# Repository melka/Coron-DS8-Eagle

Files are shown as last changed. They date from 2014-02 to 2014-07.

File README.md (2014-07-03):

# Coron DS8 Clone

Eagle project for the [Coron DS8 Clone by Marc Bareille](http://m.bareille.free.fr/ds7clone/ds8.htm)

[BOM on Mouser](http://www.mouser.com/ProjectManager/ProjectDetail.aspx?AccessID=e1b7458c28)

Block diagrams: 
http://m.bareille.free.fr/ds7clone/ds8_rev1_wiring1.gif

Original schematics:
http://m.bareille.free.fr/ds7clone/ds8_schem_rev1.pdf

### TODO
*   Add diode on power supply for reverse protection.

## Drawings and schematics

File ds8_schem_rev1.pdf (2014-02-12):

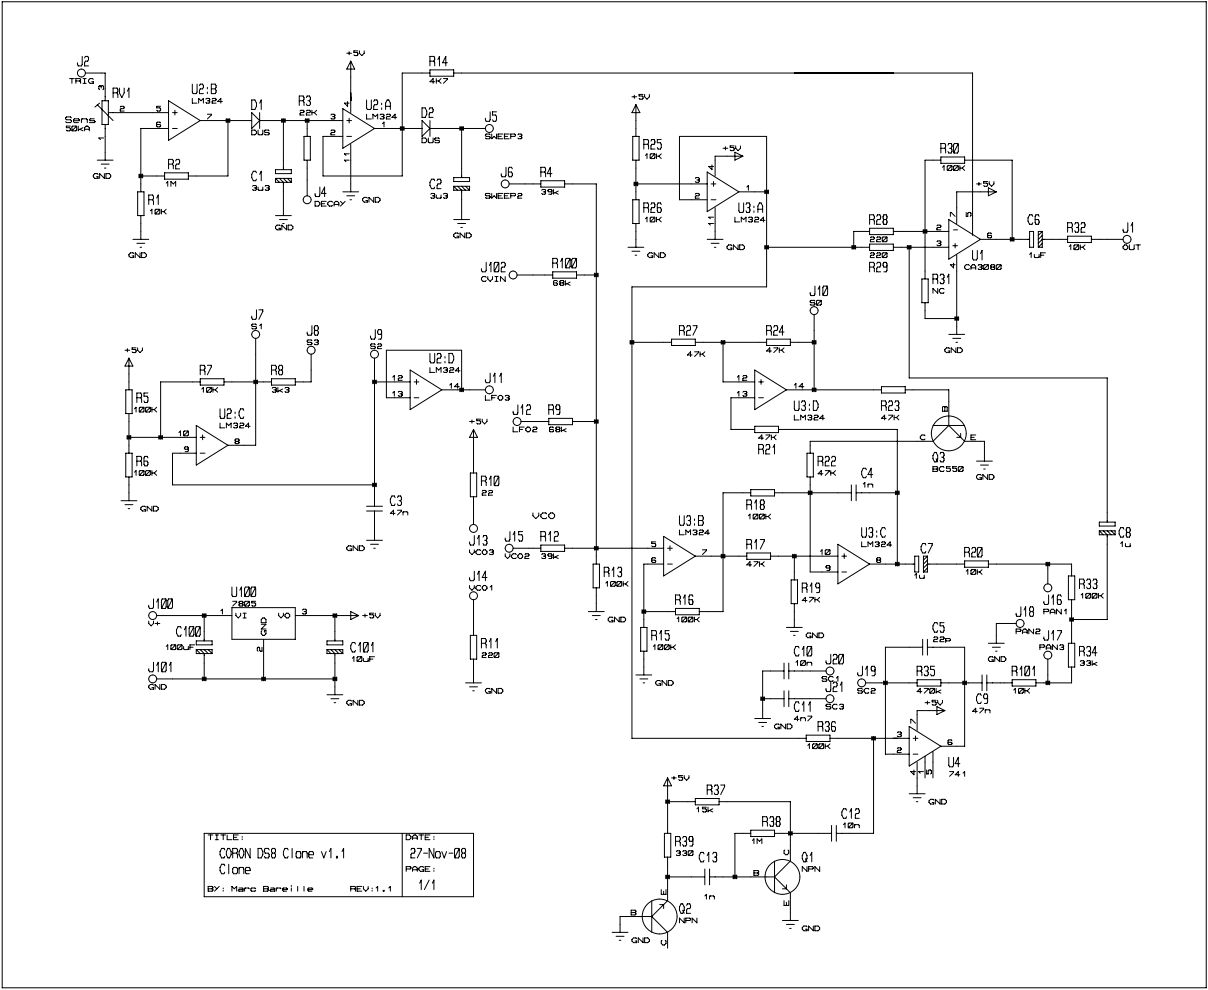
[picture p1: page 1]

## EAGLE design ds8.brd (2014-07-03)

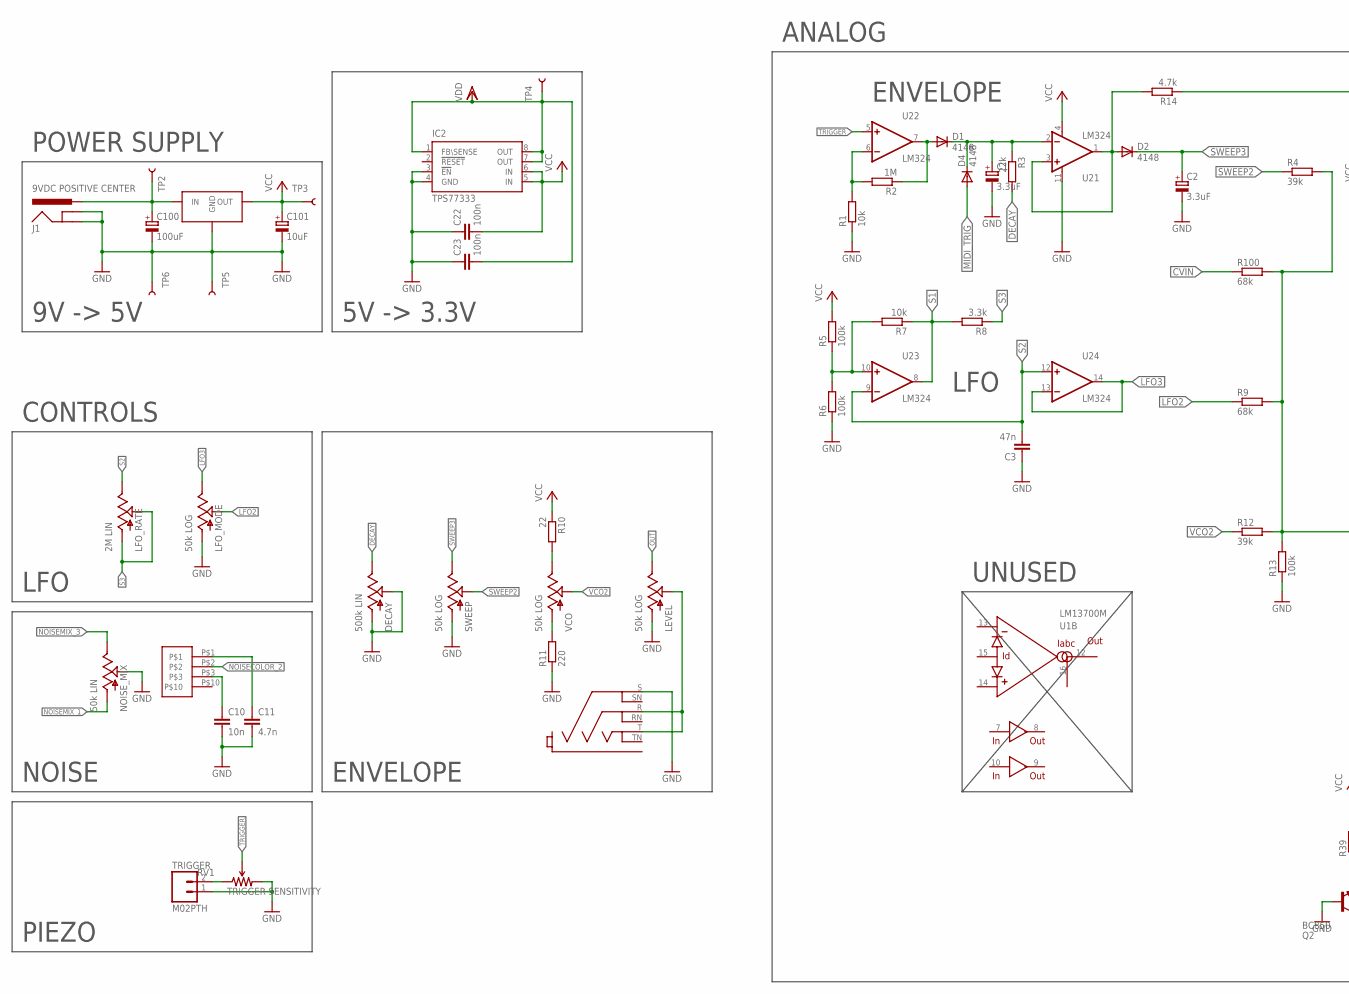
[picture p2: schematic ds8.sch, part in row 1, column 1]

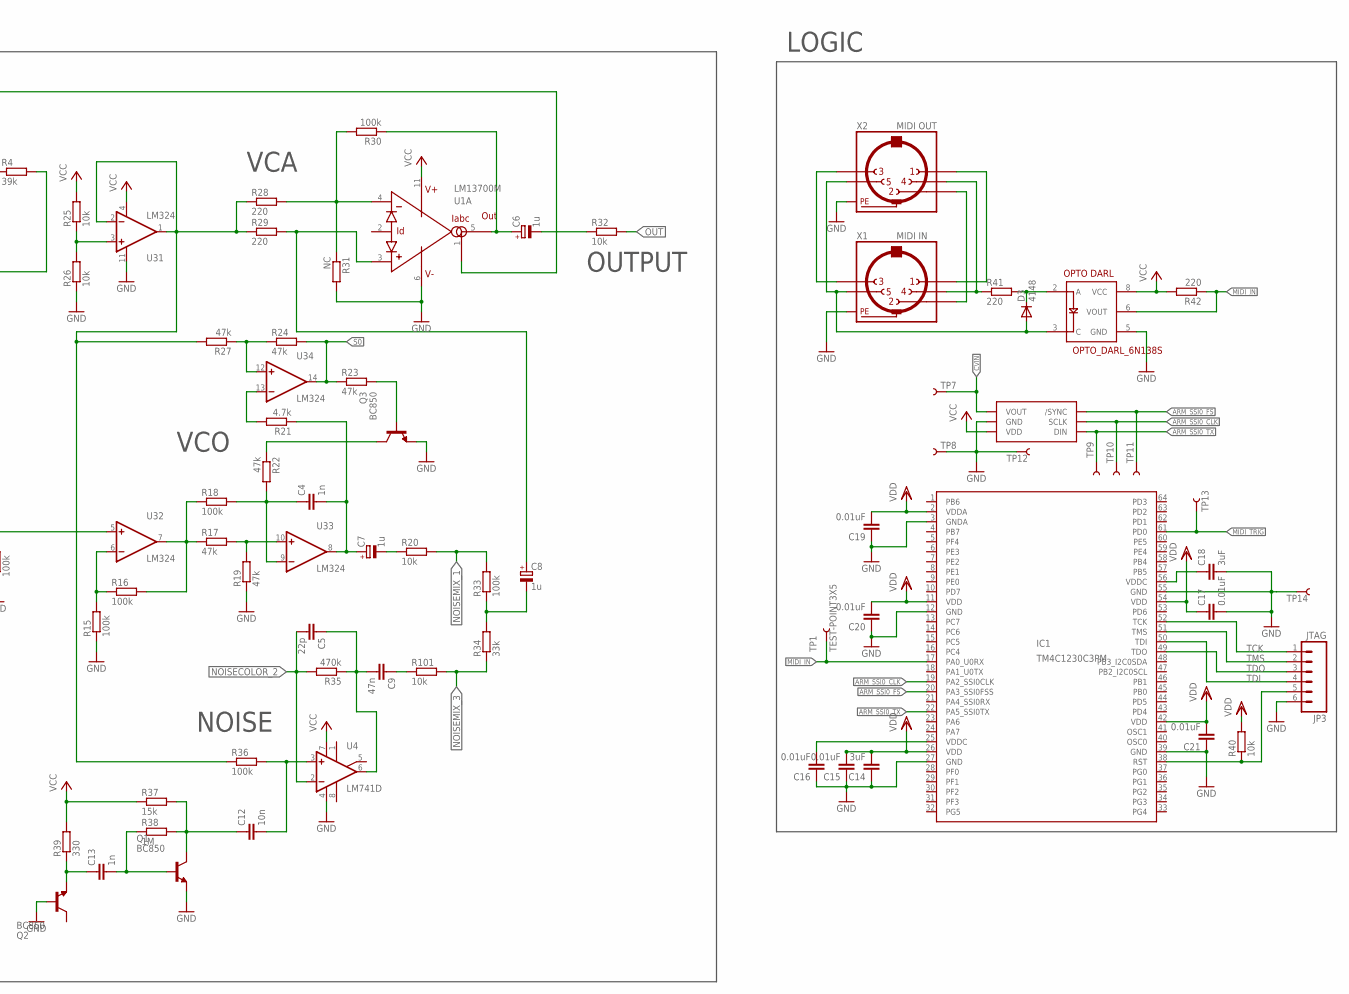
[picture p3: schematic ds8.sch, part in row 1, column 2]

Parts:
C1, C2: 3.3uF; R/2012-12R
C3, C9: 47n; C1206
C4, C13: 1n; C1206
C5: 22p; C1206
C6, C7, C8: 1u; R/2012-12R
C10, C12: 10n; C1206
C11: 4.7n; C1206
C14, C18: 3uF; C1206
C15, C16, C17, C19, C20, C21: 0.01uF; C1206
C22, C23: 100n; C1206
C100: 100uF; PANASONIC_D
C101: 10uF; R/2012-12R
D1, D2, D3, D4: 4148; MINIMELF
DECAY: 500k LIN; ALPS_POT_KIT
IC1: TM4C1230C3PM; LQFP_64
IC2: TPS77333; SOP-08
IC3: DAC7512; SOT-23-6
J1: 9VDC POSITIVE CENTER; POWER_JACK_PTH_LOCK
JP3: JTAG; 1X06
LEVEL: 50k LOG; ALPS_POT_KIT
LFO_MODE: 50k LOG; ALPS_POT_KIT
LFO_RATE: 2M LIN; ALPS_POT_KIT
NOISE_MIX: 50k LIN; ALPS_POT_KIT
Q1, Q2, Q3: BC850; SOT23
R1, R7: 10k; R0805
R2: 1M; R0805
R3: 22k; R0805
R4, R12: 39k; R0805
R5, R6, R13, R15: 100k; R0805
R8: 3.3k; R0805
R9, R100: 68k; R0805
R10: 22; R0805
R11, R41, R42: 220; R0805
R14: 4.7k; R0805
R16, R18, R30, R33, R36: 100k; M0805
R17, R19, R22, R23, R24, R27: 47k; M0805
R20, R25, R26, R32, R40, R101: 10k; M0805
R21: 4.7k; M0805
R28, R29: 220; M0805
R31: NC; M0805
R34: 33k; M0805
R35: 470k; M0805
R37: 15k; M0805
R38: 1M; M0805
R39: 330; M0805
RV1: TRIGGER SENSITIVITY; TRIMPOT-5MM-V2
SWEEP: 50k LOG; ALPS_POT_KIT
TP1, TP2, TP3, TP4, TP5, TP6, TP7, TP8, TP9, TP10, TP11, TP12, TP13, TP14: TEST-POINT3X5; PAD.03X.05
TRIGGER: M02PTH; 1X02
U1: LM13700M; DS8_SO16
U2, U3: LM324; SOIC-14
U4: LM741D; SO08
U100: VREG-7805-DPAK2
U$1: 6.35MMJACK; NMJ6HCD3
U$3: ALPS_SRBV
U$4: OPTO_DARL_6N138S; 8-SMD
VCO: 50k LOG; ALPS_POT_KIT
X1: MIDI IN; MAB5SH
X2: MIDI OUT; MAB5SH

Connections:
9VDC: C100.+, J1.PWR, TP2.P$1, U100.VIN (IN)
ARM_SSI0_CLK: IC1.19 (PA2_SSI0CLK), IC3.5 (SCLK), TP10.P$1
ARM_SSI0_FS: IC1.20 (PA3_SSI0FSS), IC3.6 (/SYNC), TP11.P$1
ARM_SSI0_TX: IC1.22 (PA5_SSI0TX), IC3.4 (DIN), TP9.P$1
CVIN: IC3.1 (VOUT), R100.1, TP7.P$1
DECAY: DECAY.P$1 (E), R3.2
GND: C1.-, C2.-, C3.1, C10.2, C11.2, C14.1, C15.1, C16.1, C17.2, C18.2, C19.1, C20.1, C21.1, C22.1, C23.1, C100.-, C101.-, DECAY.P$2 (S), DECAY.P$3 (A), IC1.3 (GNDA), IC1.12 (GND), IC1.27 (GND), IC1.39 (GND), IC1.55 (GND), IC2.3 (!EN), IC2.4 (GND), IC3.2 (GND), J1.GND, J1.GNDBREAK, JP3.6, LEVEL.P$3 (A), LFO_MODE.P$3 (A), NOISE_MIX.P$2 (S), Q1.2 (E), Q2.1 (B), Q3.2 (E), R1.1, R6.1, R11.1, R13.1, R15.1, R19.1, R26.1, R31.2, RV1.C (CW), SWEEP.P$3 (A), TP5.P$1, TP6.P$1, TP8.P$1, TP12.P$1, TP14.P$1, TRIGGER.1, U1.6 (V-), U2.11 (V-), U3.11 (V-), U4.4 (V-), U100.GND, U$1.S, U$4.5 (GND), X1.PE, X1.PE@ (PE), X2.PE, X2.PE@ (PE)
LFO2: LFO_MODE.P$2 (S), R9.1
LFO3: LFO_MODE.P$1 (E), U2.13 (-IN), U2.14 (OUT)
MIDI_IN: IC1.17 (PA0_U0RX), R42.1, TP1.P$1, U$4.6 (VOUT)
MIDI_TRIG: D4.A, IC1.61 (PD0), TP13.P$1
unnamed: D1.A, R2.1, U2.7 (OUT)
unnamed: R1.2, R2.2, U2.6 (-IN)
unnamed: C1.+, D1.C, D4.C, R3.1, U2.2 (-IN)
unnamed: D2.A, R14.2, U2.1 (OUT), U2.3 (+IN)
unnamed: R5.1, R6.2, R7.2, U2.10 (+IN)
unnamed: X1.1, X2.1
unnamed: R15.2, R16.1, U3.6 (-IN)
unnamed: R4.2, R9.2, R12.2, R13.2, R100.2, U3.5 (+IN)
unnamed: R16.2, R17.1, R18.1, U3.7 (OUT)
unnamed: R17.2, R19.2, U3.10 (+IN)
unnamed: C4.1, R18.2, R22.2, U3.9 (-IN)
unnamed: C8.-, R33.1, R34.2
unnamed: C7.-, R20.1
unnamed: C4.2, C7.+, R21.1, U3.8 (OUT)
unnamed: Q3.3 (C), R22.1
unnamed: R21.2, U3.13 (-IN)
unnamed: R24.1, R27.1, U3.12 (+IN)
unnamed: R41.1, X1.4, X2.4
unnamed: Q3.1 (B), R23.2
unnamed: R27.2, R28.1, R29.1, R36.1, U3.1 (OUT), U3.2 (-IN)
unnamed: C9.1, R101.1
unnamed: R25.1, R26.2, U3.3 (+IN)
unnamed: R28.2, R30.2, R31.1, U1.4 (-IN)
unnamed: C8.+, R29.2, U1.3 (+IN)
unnamed: C6.-, R32.1
unnamed: D3.C, R41.2, U$4.2 (A)
unnamed: C6.+, R30.1, U1.5 (OUT)
unnamed: C5.1, C9.2, R35.1, U4.6 (OUT)
unnamed: C12.1, Q1.3 (C), R37.2, R38.2
unnamed: C12.2, R36.2, U4.3 (+IN)
unnamed: R14.1, U1.1 (IABC)
unnamed: C13.2, Q1.1 (B), R38.1
unnamed: C13.1, Q2.2 (E), R39.1
unnamed: RV1.A (CCW), TRIGGER.2
unnamed: D3.A, U$4.3 (C), X1.5, X2.5
unnamed: C18.1, IC1.56 (VDDC)
unnamed: R10.2, VCO.P$1 (E)
unnamed: R11.2, VCO.P$3 (A)
unnamed: C10.1, U$3.P$3
unnamed: C11.1, U$3.P$1
unnamed: X1.2, X2.2
unnamed: C16.2, IC1.25 (VDDC)
unnamed: X1.3, X2.3
unnamed: LEVEL.P$2 (S), U$1.R, U$1.T
NOISECOLOR_2: C5.2, R35.2, U4.2 (-IN), U$3.P$2
NOISEMIX_1: NOISE_MIX.P$3 (A), R20.2, R33.2
NOISEMIX_3: NOISE_MIX.P$1 (E), R34.1, R101.2
OUT: LEVEL.P$1 (E), R32.2
RST: IC1.38 (RST), JP3.5, R40.1
S0: R23.1, R24.2, U3.14 (OUT)
S1: R7.1, R8.2, U2.8 (OUT)
S2: C3.2, LFO_RATE.P$1 (E), U2.9 (-IN), U2.12 (+IN)
S3: LFO_RATE.P$2 (S), LFO_RATE.P$3 (A), R8.1
SWEEP2: R4.1, SWEEP.P$2 (S)
SWEEP3: C2.+, D2.C, SWEEP.P$1 (E)
TCK: IC1.52 (TCK), JP3.1
TDI: IC1.50 (TDI), JP3.4
TDO: IC1.49 (TDO), JP3.3
TMS: IC1.51 (TMS), JP3.2
TRIGGER: RV1.B (WIPER), U2.5 (+IN)
VCC: C22.2, C101.+, IC2.5 (IN), IC2.6 (IN), IC3.3 (VDD), R5.2, R10.1, R25.2, R37.1, R39.2, R42.2, TP3.P$1, U1.11 (V+), U2.4 (V+), U3.4 (V+), U4.7 (V+), U100.VOUT (OUT), U$4.8 (VCC)
VCO2: R12.1, VCO.P$2 (S)
VDD: C14.2, C15.2, C17.1, C19.2, C20.2, C21.2, C23.2, IC1.2 (VDDA), IC1.11 (VDD), IC1.26 (VDD), IC1.42 (VDD), IC1.54 (VDD), IC2.1 (FB\SENSE), IC2.7 (OUT), IC2.8 (OUT), R40.2, TP4.P$1

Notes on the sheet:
ENVELOPE
VCA
OUTPUT
NOISE
VCO
LFO
CONTROLS
PIEZO
POWER SUPPLY
9V -> 5V
5V -> 3.3V
LOGIC
UNUSED
ANALOG

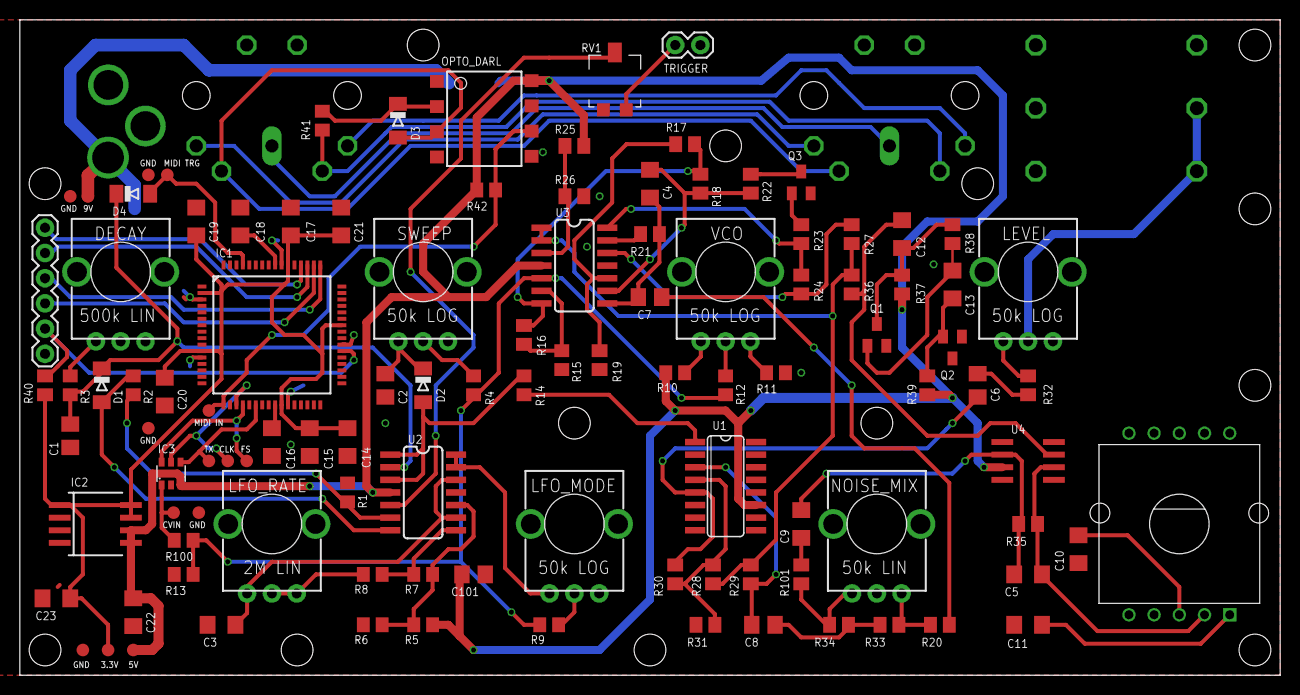
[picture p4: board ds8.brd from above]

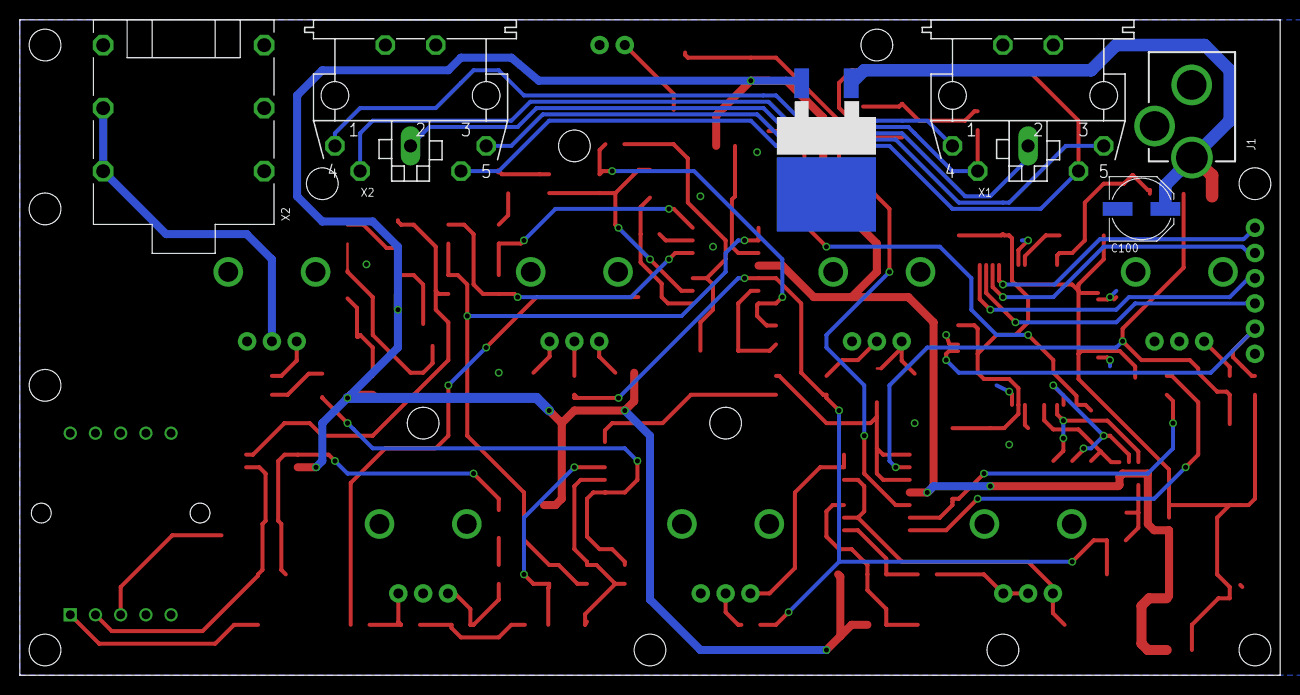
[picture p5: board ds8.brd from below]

Board: 4 copper layers, 127.0 x 66.0 mm, 114 parts (6 on the bottom side), 74 nets.

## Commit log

2014-02-12 Added README and link to BOM on Mouser
2014-02-12 added some text infos
    [ds8.sch]
2014-02-13 added regulator for mcu
    [ds8.brd, ds8.sch]
2014-02-13 added dac
    [ds8.brd, ds8.sch]
2014-02-13 clean up
    [ds8.brd, ds8.sch]
2014-02-13 wire conflicts
    [ds8.brd, ds8.sch]
2014-02-14 added optocoupler
    [ds8.brd, ds8.sch]
2014-02-14 added SW debug on midi connector
    [ds8.brd, ds8.sch]
2014-02-14 added midi trigger
    [ds8.brd, ds8.sch]
2014-02-17 Board retouted
    - Cleaned the schematic
    - Board rerouted with through hole pots and new connectors
    - Lots of little stuff
    [ds8.brd, ds8.sch]
2014-02-17 resistor upside down
    [ds8.sch]
2014-03-02 added more decoupling to vdd pins. jtag in place with a reset line
    [ds8.brd, ds8.sch]
2014-03-18 TODO : Check JTAG
    Don't we need to have at least a common ground for the JTAG connection ? What about using this kind of supposedly standard header ? http://www.keil.com/support/man/docs/ulinkpro/ulinkpro_hw_if_jtag10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
    Done : board rerouted, added test points, added screw holes, moved a few things around, almost ready to be produced once we are sure about the JTAG stuff & checked the components one last time.
    [ds8.brd, ds8.sch]
2014-03-20 Mech design revisions
    Moved screw holes and some little components for assembly
    [ds8.brd]
2014-04-03 PCB v1 Release
    Added GND on JTAG and a MIDI Passthrough connector
    [ds8.brd, ds8.sch]
2014-07-03 Prototype v1
    Version that has been produced via Seeed Studio.
    Added todolist to readme.md.
    [ds8.brd]
2014-07-03 Previous commit mangled up the board file, here it is again. Not exactly the board used for prototyping but same functionnality.
    [ds8.brd, ds8.sch]

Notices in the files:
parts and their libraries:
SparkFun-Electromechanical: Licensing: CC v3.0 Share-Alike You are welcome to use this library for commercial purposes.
